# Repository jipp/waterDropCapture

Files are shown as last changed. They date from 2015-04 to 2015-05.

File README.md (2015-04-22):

# waterDropCapture

## The following features are implemented
* the sensor will trigger the DSLR assuming a hight of 0,5m

## Installation
Put the waterDropCapture folder into the local Arduino folder.

## Additional files
EAGLE files included:
* Circuit diagram
* Board layout

OpenSCAD files included:
* tube to hold the sensor and be plugged over a bottle

## Info
This was developed 1st for a Nikon, but as a 2.5mm Jack is used to connect the camera any camera adapter should work.
The tube should fit on many water bottles.

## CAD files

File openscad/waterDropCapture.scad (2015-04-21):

//Library
use <text_on.scad>

//general settings
$fn = 64;

//buffer for printing
buffer = 1;

//sensor
sensorWidth = 6;
sensorHight = 6;
sensorDepth = 3;
sensorSink = 15;
pathHeight = 3;

//cylinder
cylinderHeight = 60;
cylinderInnerRadius1 = 13;
cylinderInnerRadius2 = 16;
cylinderOuterRadius = 19;

//ring
fixumWidth = 5;
fixumThickness = 1;

//text
text="Tropfenfalle";
textDepth = 1;
textHeight = 7;

//calculated
distance = (cylinderOuterRadius + cylinderInnerRadius1) / 2;

//sensor 
module sensor() {
    //sensor 1
	translate([-sensorWidth/2, distance-sensorDepth/2, -buffer]) {
		cube([sensorWidth, sensorDepth, sensorSink+buffer]);
	}
    //path 1
    translate([-sensorWidth/2, distance, -buffer]) {
		cube([sensorWidth, cylinderOuterRadius-distance+buffer, pathHeight+buffer]);
	}
    //sensor 2
	translate([-sensorWidth/2, -distance-sensorDepth/2, -buffer]) {
		cube([sensorWidth, sensorDepth, sensorSink+buffer]);
	}
    //path 2
	translate([-sensorWidth/2, -cylinderOuterRadius-buffer, -buffer]) {
		cube([sensorWidth, cylinderOuterRadius-distance+buffer, pathHeight+buffer]);
	}
    //light tunnel
	translate([0, 0, sensorSink-sensorWidth/2+1]) {
		rotate([0, 90, 90]) {
			translate([0, 0, -distance]) {
				cylinder(r=sensorWidth/2-buffer, h=2*distance);
			}
		}
	}
}

//Ring
module ring() {
	difference() {
		cylinder(r=cylinderOuterRadius, h=cylinderHeight);
		translate([0, 0, cylinderHeight / 2-buffer]) {
			cylinder(r1=cylinderInnerRadius1, r2=cylinderInnerRadius2, h=cylinderHeight/2+2*buffer);
		}
		translate([0, 0, -1]) {
			cylinder(r=cylinderInnerRadius1, h=cylinderHeight/2+2*buffer);
		}
        text_on_cylinder(t=text, r=cylinderOuterRadius-textDepth, h=cylinderHeight, direction="ltr", font="Liberation Mono", size=textHeight, extrusion_height=textDepth+buffer);
	}
}

//fix rings
module fixRings() {
    //lower ring
	difference() {
        translate([0, 0, sensorSink+buffer]) {
			cylinder(r=cylinderOuterRadius+buffer, h=fixumThickness);
        }
        translate([0, 0, sensorSink]) {
 			cylinder(r=cylinderOuterRadius-buffer, h=fixumThickness+2*buffer);
		}
	}
    //upper ring
	difference() {
        translate([0, 0, sensorSink+fixumWidth+buffer]) {
			cylinder(r=cylinderOuterRadius+buffer, h=fixumThickness);
        }
    	translate([0, 0, sensorSink+fixumWidth]) {
            cylinder(r=cylinderOuterRadius-buffer, h=fixumThickness+2*buffer);
		}
	}
}

//cable through rings
module fixum() {
    //fixum 1
	translate([-sensorWidth/2, cylinderOuterRadius, sensorSink-2*buffer]) {
		cube([sensorWidth, 2*buffer, fixumWidth+4*buffer]);
	}
    //fixum2
	translate([-sensorWidth/2, -cylinderOuterRadius-2, sensorSink-2*buffer]) {
		cube([sensorWidth, 2*buffer, fixumWidth+4*buffer]);
	}
}

//major form
color("red")
difference() {
	ring();
	sensor();
}

//additional ring
color("blue")
difference() {
	fixRings();
	fixum();
}

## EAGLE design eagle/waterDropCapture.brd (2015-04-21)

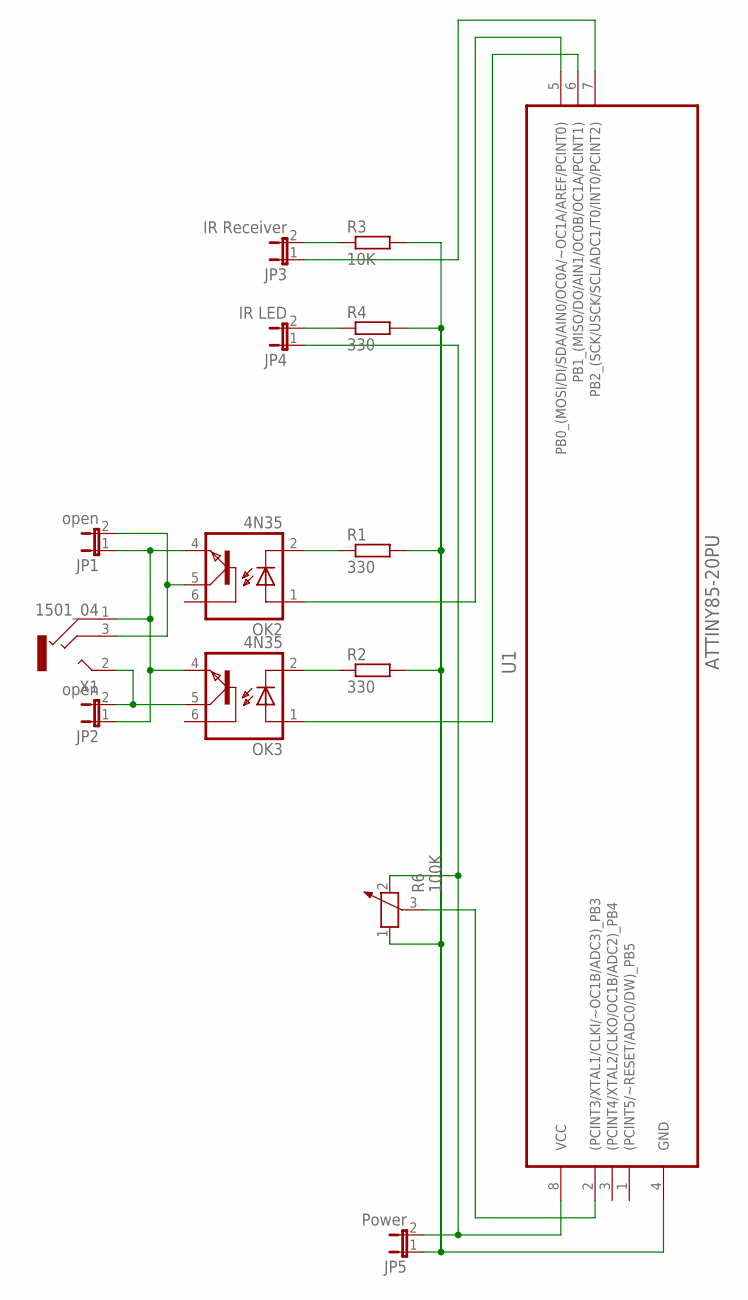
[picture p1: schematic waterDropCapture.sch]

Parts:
JP1, JP2: open; JP1
JP3: IR Receiver; JP1
JP4: IR LED; JP1
JP5: Power; JP1
OK2, OK3: 4N35; DIL06
R1, R2, R4: 330; 0207/10
R3: 10K; 0207/10
R6: 100K; PT-10
U1: ATTINY85-20PU; DIP254P762X533-8
X1: 1501_04; 1501_05

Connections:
unnamed: OK2.2 (C), R1.1
unnamed: OK3.2 (C), R2.1
unnamed: JP1.1, JP2.1, OK2.4 (EMI), OK3.4 (EMI), X1.1
unnamed: OK2.1 (A), U1.5 (PB0_(MOSI/DI/SDA/AIN0/OC0A/~OC1A/AREF/P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)
unnamed: JP2.2, OK3.5 (COL), X1.2
unnamed: JP5.1, R1.2, R2.2, R3.2, R4.2, R6.1, U1.4 (GND)
unnamed: OK3.1 (A), U1.6 (PB1_(MISO/DO/AIN1/OC0B/OC1A/PCINT1))
unnamed: JP4.2, R4.1
unnamed: JP1.2, OK2.5 (COL), X1.3
unnamed: JP4.1, JP5.2, R6.2, U1.8 (VCC)
unnamed: JP3.2, R3.1
unnamed: JP3.1, U1.7 (PB2_(SCK/USCK/SCL/ADC1/T0/INT0/PCINT2))
unnamed: R6.3, U1.2 ((PCINT3/XTAL1/CLKI/~OC1B/ADC3)_PB3)

Board: 2 copper layers, 14 parts (0 on the bottom side), 13 nets, no tracks yet.

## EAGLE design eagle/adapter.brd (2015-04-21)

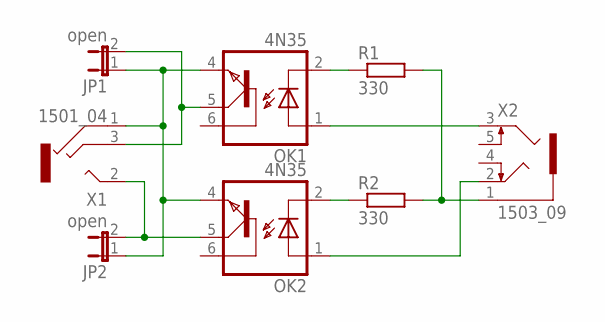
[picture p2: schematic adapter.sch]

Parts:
JP1, JP2: open; JP1
OK1, OK2: 4N35; DIL06
R1, R2: 330; 0207/10
X1: 1501_04; 1501_05
X2: 1503_09

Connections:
unnamed: JP1.1, JP2.1, OK1.4 (EMI), OK2.4 (EMI), X1.1
unnamed: OK1.2 (C), R1.1
unnamed: OK2.2 (C), R2.1
unnamed: R1.2, R2.2, X2.1
unnamed: JP1.2, OK1.5 (COL), X1.3
unnamed: JP2.2, OK2.5 (COL), X1.2
unnamed: OK2.1 (A), X2.2
unnamed: OK1.1 (A), X2.3

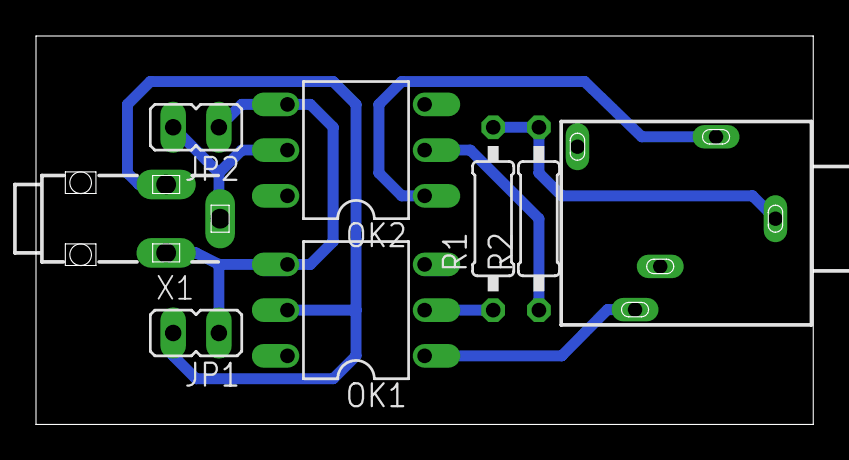
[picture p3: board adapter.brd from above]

Board: 2 copper layers, 43.2 x 21.6 mm, 8 parts (0 on the bottom side), 8 nets.

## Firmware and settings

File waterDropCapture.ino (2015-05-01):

#define ATTINY

#include <Streaming.h>

/*
 * light blue -> sender
 * black -> receiver
 */

// ATtiny85
// A0, A1 -> 5, 6
// Digital 2, 3, 4 -> 7, 2, 3
const int sensorPin = A0;
const int tunePin = A1;
const int focusPin = 2;
const int shutterPin = 3;
const int ledPin = 4;

const int height = 0.50; // cm
const int shutDelay = sqrt(height * 2 / 9.81) * 1000; // calculated by falling drop s=0.5*9.81*t^2
const int holdDelay = 100; // time to keep the bottom pressed and release bottom
const int photoDelay = 5000; // minimum time between release and press
const int sensibility = 25; // depending on the surrounded light
int sensorValue = 1023;
int sensorValueCalibrated = 1023;
int tuneValue = 0;

void setup() {
#ifndef ATTINY
	Serial.begin(9600);
	Serial << "calculated shutDelay: " << shutDelay << endl;
#endif
	setPin();
	calibrateSensorValue();
	pressFocus();
}

void loop() {
	sensorValue = analogRead(sensorPin);
	tuneValue = map(analogRead(tunePin), 0, 1023, -50, 50); // between -50 ... 50 ms tolerance
	if (sensorValue + sensibility < sensorValueCalibrated) {
#ifndef ATTINY
		Serial << endl << "Sensor Value: " << sensorValue << endl;
		Serial << "tuneValue: " << tuneValue << endl;
#endif
		digitalWrite(ledPin, HIGH);
		delay(shutDelay + tuneValue);
		pressShut();
		delay(holdDelay);
		releaseShut();
		releaseFocus();
		delay(photoDelay);
		pressFocus();
		digitalWrite(ledPin, LOW);
	}
}

void setPin() {
	pinMode(ledPin, OUTPUT);
	pinMode(focusPin, OUTPUT);
	pinMode(shutterPin, OUTPUT);
	digitalWrite(ledPin, LOW);
	digitalWrite(focusPin, LOW);
	digitalWrite(shutterPin, LOW);
}

void calibrateSensorValue() {
	for (int i = 0; i < 2000; i++) {
		sensorValue = analogRead(sensorPin);
		if (sensorValue < sensorValueCalibrated) {
			sensorValueCalibrated = sensorValue;
		}
	}
#ifndef ATTINY
	Serial << "Calibrated Value: " << sensorValueCalibrated << endl;
#endif
}

void pressFocus() {
	digitalWrite(focusPin, HIGH);
#ifndef ATTINY
	Serial << "pressed focus" << endl;
#endif
}

void pressShut() {
	digitalWrite(shutterPin, HIGH);
#ifndef ATTINY
	Serial << "pressed shut" << endl;
#endif
}

void releaseFocus() {
	digitalWrite(focusPin, LOW);
#ifndef ATTINY
	Serial << "released focus" << endl;
#endif
}

void releaseShut() {
	digitalWrite(shutterPin, LOW);
#ifndef ATTINY
	Serial << "released shut" << endl;
#endif
}

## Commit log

2015-04-21 for 3D printer
    [waterDropCapture.scad]
2015-04-21 added circuit drawing and board layout
    [adapter.brd, adapter.sch, waterDropCapture.brd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]
2015-05-01 remove include for Arduino.h
